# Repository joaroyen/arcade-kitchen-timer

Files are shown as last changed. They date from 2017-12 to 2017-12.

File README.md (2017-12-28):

# Arcade Kitchen Timer

The Arcade Kitchen Timer Mini is my first attempt at designing and developing a product using electronics, programming and 3D modelling. See [Wiki](https://github.com/joaroyen/arcade-kitchen-timer/wiki) for details about the project.

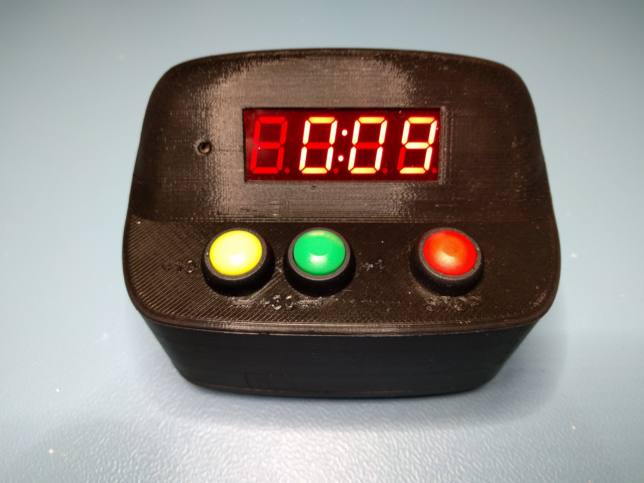
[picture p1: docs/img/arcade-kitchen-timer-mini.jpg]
Arcade Kitchen Timer Mini


> PS: Don't expect much activity in this repository after it is published.

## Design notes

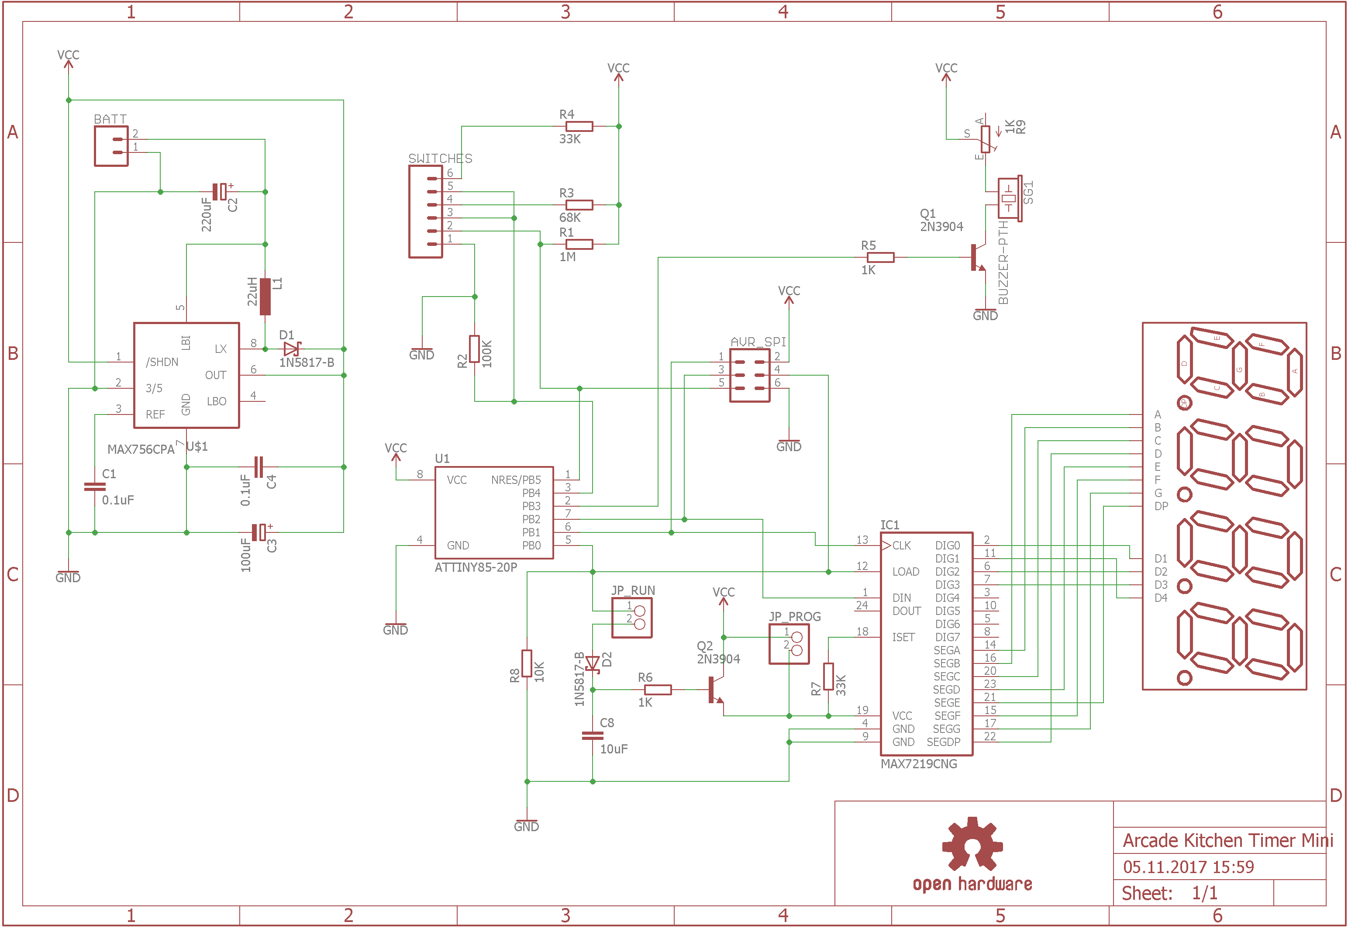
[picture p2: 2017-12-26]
docs/img/mini-electronics-schematic.png

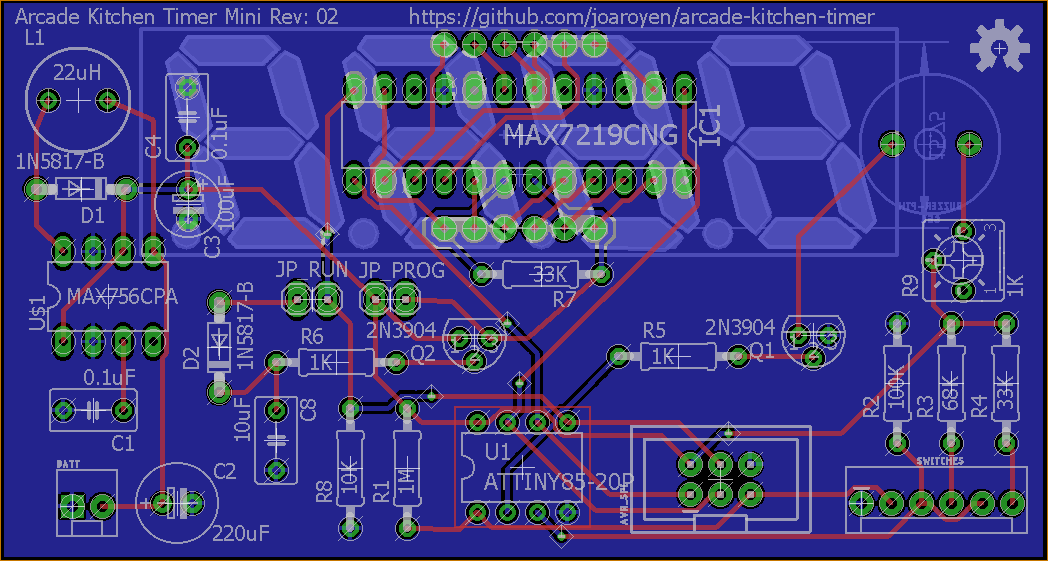
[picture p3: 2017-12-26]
docs/img/mini-electronics-board.png

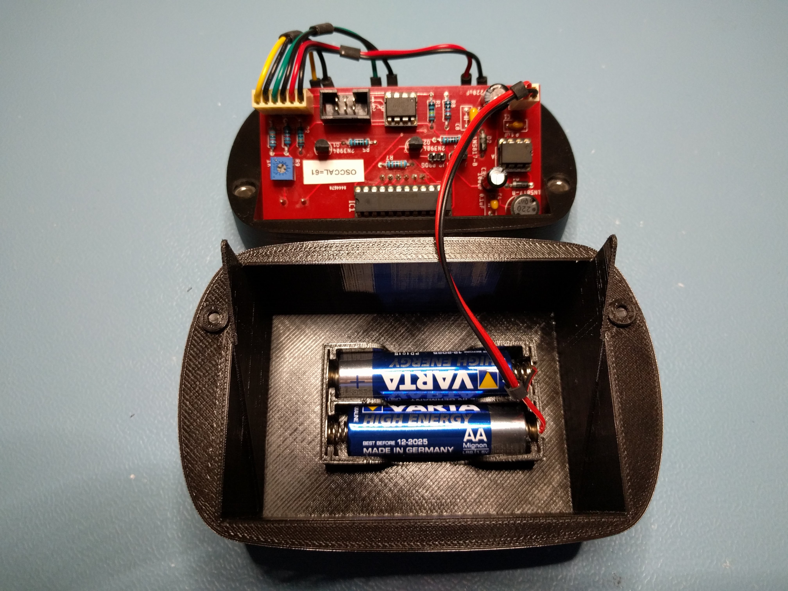
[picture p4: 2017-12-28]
docs/img/arcade-kitchen-timer-mini-open.jpg

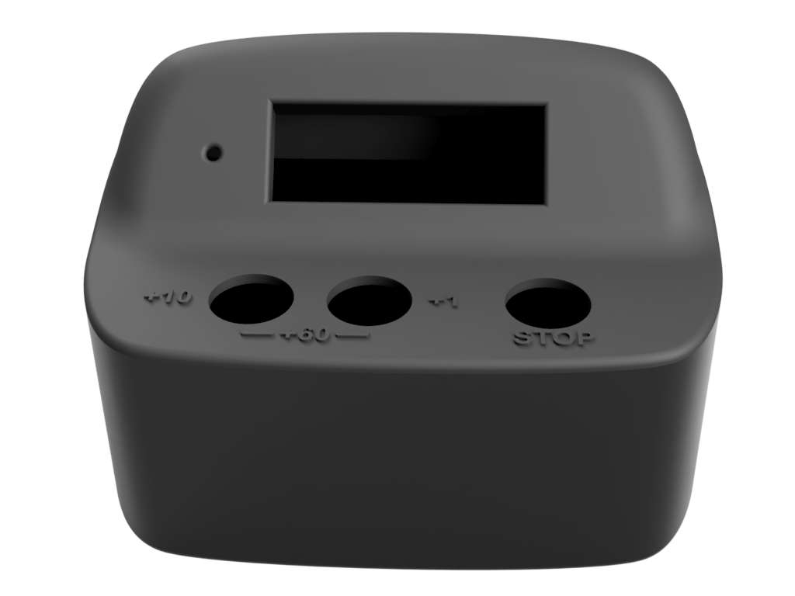
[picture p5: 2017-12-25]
docs/img/mini-enclosure-render.png

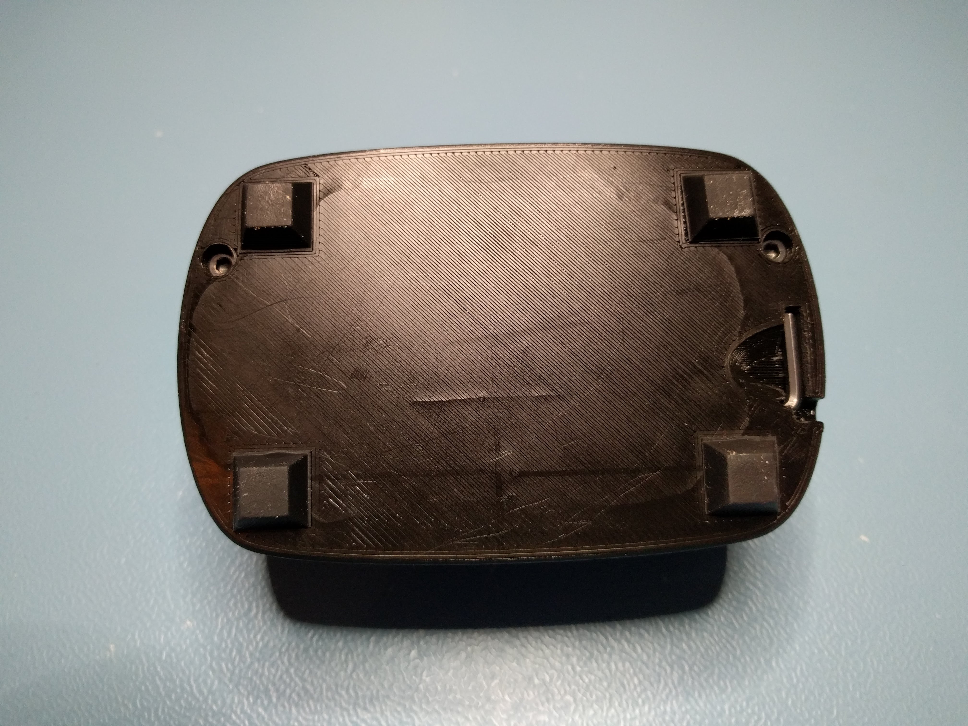
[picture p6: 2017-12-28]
docs/img/arcade-kitchen-timer-mini-bottom.jpg

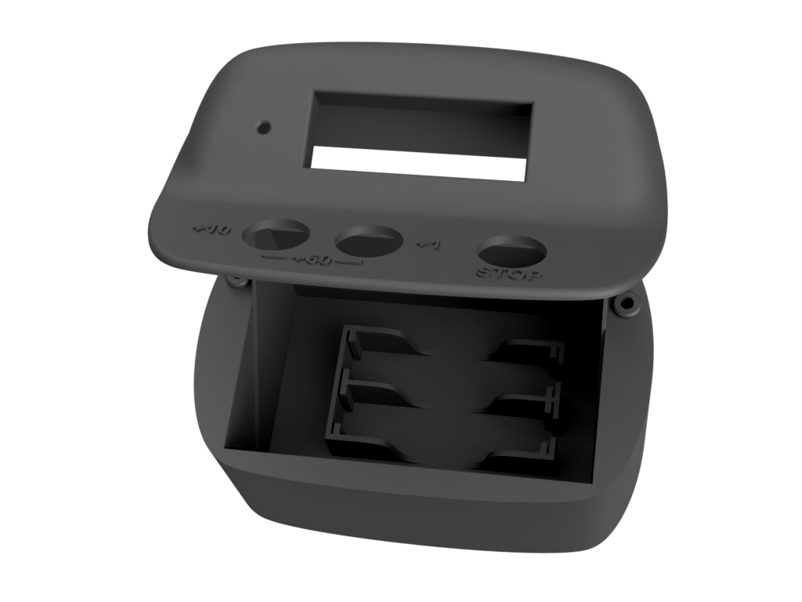
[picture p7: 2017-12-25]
docs/img/mini-enclosure-render-open.png

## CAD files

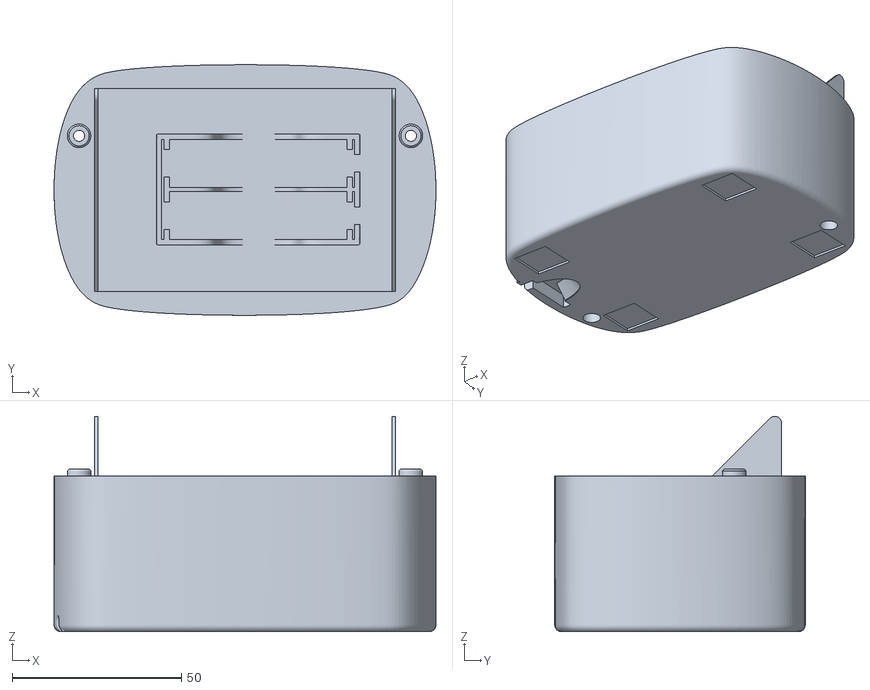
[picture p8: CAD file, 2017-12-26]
enclosure/Enclosure Case.stl
112.8 x 74.0 x 63.6

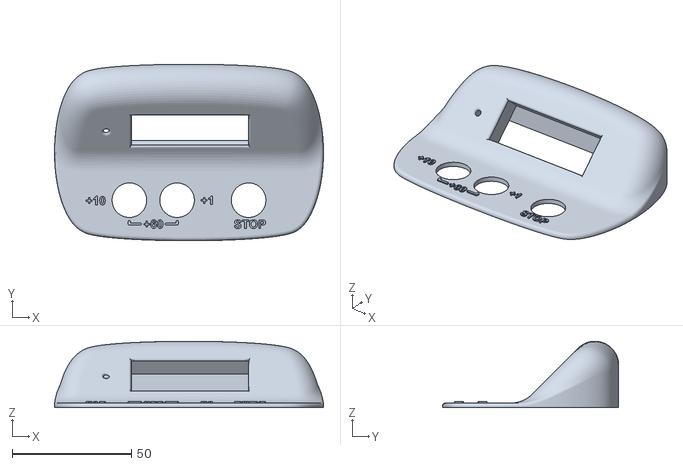
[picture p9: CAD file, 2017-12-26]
enclosure/Enclosure Top.stl
112.8 x 74.0 x 27.8

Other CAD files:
enclosure/Mini Enclosure v9.f3d

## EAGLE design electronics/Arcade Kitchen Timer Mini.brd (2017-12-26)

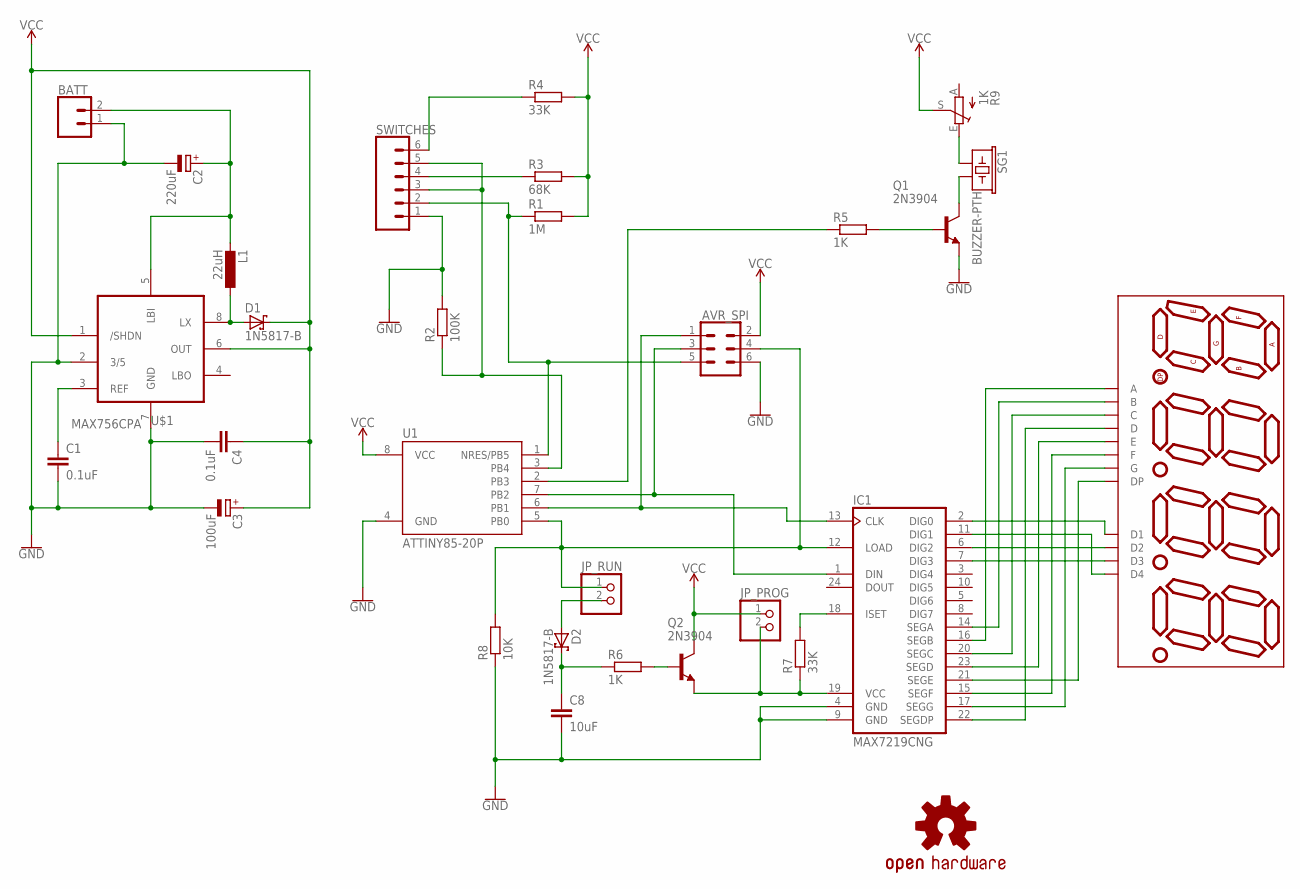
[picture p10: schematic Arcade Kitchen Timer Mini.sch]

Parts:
AVR_SPI: CONN_03X2SHROUD; 2X3-SHROUDED
BATT: CONN_02POLAR; MOLEX-1X2
C1, C4: 0.1uF; C050-035X075
C2: 220uF; E2,5-7
C3: 100uF; E2,5-6
C8: 10uF; C050-035X075
D1, D2: 1N5817-B; DO41-7.6
DISP1: ATA8041ARBJ; 7-SEGMENT-4DIGIT-20MM
IC1: MAX7219CNG; DIL24-3
JP_PROG: PINHD-1X2; 1X02
JP_RUN: PINHD-1X2; 1X02
L1: 22uH; 6000-XXXX-RC
LOGO1: OSHW-LOGOM; OSHW-LOGO-M
Q1, Q2: 2N3904; TO92
R1: 1M; 0207/10
R2: 100K; 0207/10
R3: 68K; 0207/10
R4, R7: 33K; 0207/10
R5, R6: 1K; 0207/10
R8: 10K; 0207/10
R9: 1K; B25P
SG1: BUZZER-PTH; BUZZER-12MM
SWITCHES: CONN_06POLAR; MOLEX-1X6
U1: ATTINY85-20P; PDIP08_300MIL
U$1: MAX756CPA; DIL08

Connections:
GND: AVR_SPI.6, BATT.1, C1.2, C2.-, C3.-, C4.2, C8.2, IC1.4 (GND), IC1.9 (GND), Q1.3 (E), R2.2, R8.1, SWITCHES.1, U1.4 (GND), U$1.2 (3/5), U$1.7 (GND)
unnamed: D1.A, L1.1, U$1.8 (LX)
unnamed: R5.1, U1.2 (PB3)
unnamed: R3.1, SWITCHES.4
unnamed: Q1.2 (B), R5.2
unnamed: AVR_SPI.5, R1.1, SWITCHES.2, U1.1 (NRES/PB5)
unnamed: D2.A, JP_RUN.2
unnamed: R4.1, SWITCHES.6
unnamed: Q2.2 (B), R6.2
unnamed: C1.1, U$1.3 (REF)
unnamed: Q1.1 (C), SG1.- (2)
unnamed: R9.E, SG1.+ (1)
unnamed: AVR_SPI.3, IC1.1 (DIN), U1.7 (PB2)
unnamed: IC1.18 (ISET), R7.2
unnamed: C8.1, D2.C, R6.1
unnamed: AVR_SPI.1, IC1.13 (CLK), U1.6 (PB1)
unnamed: AVR_SPI.4, IC1.12 (LOAD), JP_RUN.1, R8.2, U1.5 (PB0)
unnamed: IC1.19 (VCC), JP_PROG.2, Q2.3 (E), R7.1
unnamed: DISP1.11 (A), IC1.16 (SEGB)
unnamed: DISP1.7 (B), IC1.14 (SEGA)
unnamed: DISP1.4 (C), IC1.20 (SEGC)
unnamed: DISP1.2 (D), IC1.22 (SEGDP)
unnamed: DISP1.1 (E), IC1.23 (SEGD)
unnamed: DISP1.10 (F), IC1.15 (SEGF)
unnamed: DISP1.5 (G), IC1.17 (SEGG)
unnamed: DISP1.3 (DP), IC1.21 (SEGE)
unnamed: DISP1.12 (D1), IC1.2 (DIG0)
unnamed: DISP1.9 (D2), IC1.6 (DIG2)
unnamed: DISP1.8 (D3), IC1.7 (DIG3)
unnamed: DISP1.6 (D4), IC1.11 (DIG1)
unnamed: BATT.2, C2.+, L1.2, U$1.5 (LBI)
unnamed: R2.1, SWITCHES.3, SWITCHES.5, U1.3 (PB4)
VCC: AVR_SPI.2, C3.+, C4.1, D1.C, JP_PROG.1, Q2.1 (C), R1.2, R3.2, R4.2, R9.S, U1.8 (VCC), U$1.1 (/SHDN), U$1.6 (OUT)

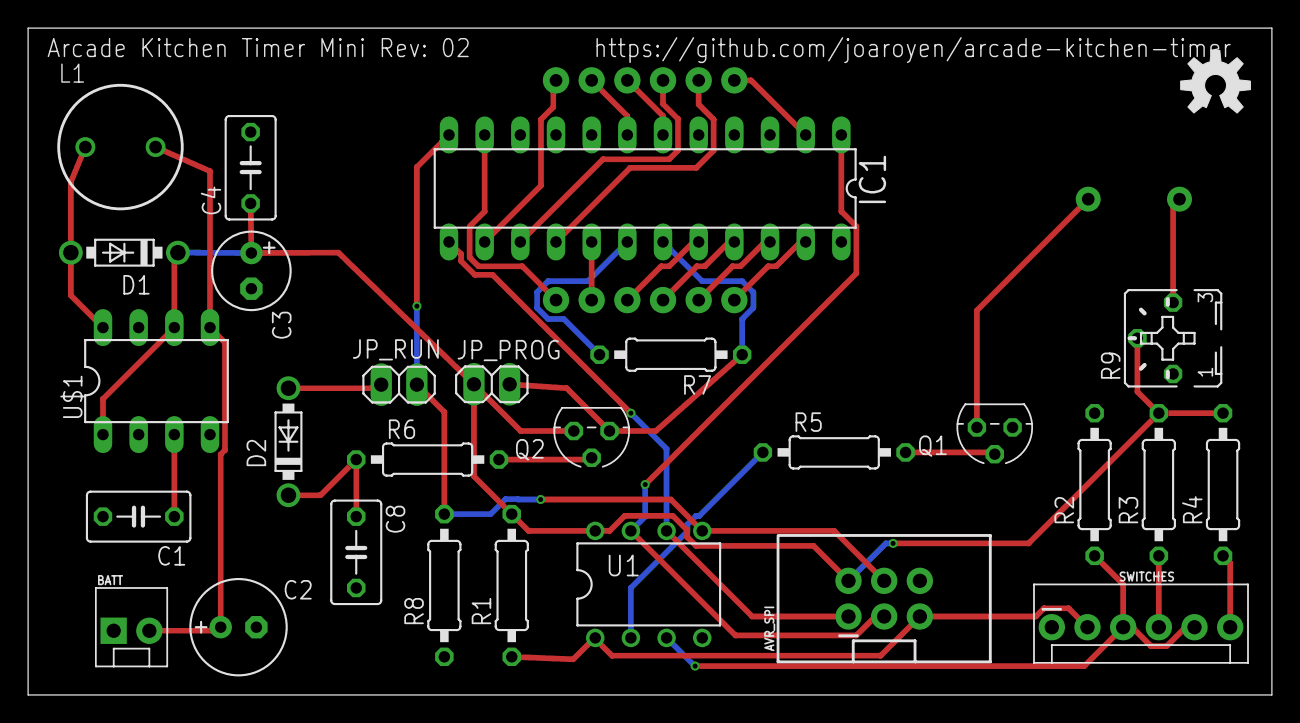
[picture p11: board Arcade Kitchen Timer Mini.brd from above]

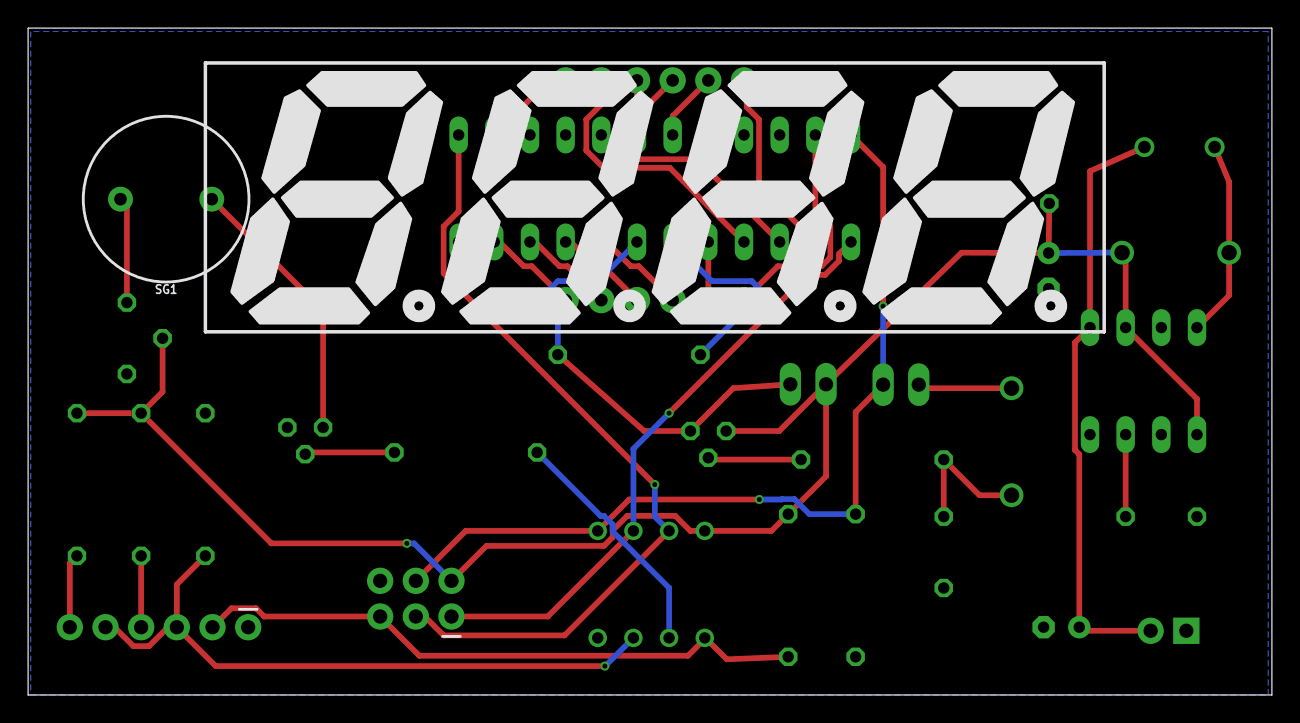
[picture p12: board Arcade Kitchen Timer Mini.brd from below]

Board: 2 copper layers, 88.6 x 47.5 mm, 30 parts (2 on the bottom side), 33 nets.

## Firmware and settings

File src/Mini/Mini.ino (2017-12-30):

#include "Common.h"
#include "Timer.h"
#include "Input.h"
#include "Display.h"
#include "Power.h"
#include "Audio.h"

Timer timer = Timer();
Input input = Input(&timer);
Display display = Display(&timer);
Power power = Power(&timer);
Audio audio = Audio(&timer);

void setup() {
  OSCCAL = DEVICE_OSCILLATOR_CALIBRATION;

  display.initialize();
  sleep();
}

void loop() {
  timer.update();

  input.read();
  display.update();
  audio.update();
  
  power.thinkAboutGoingToSleep();
}

void sleep() {
  display.shutdown();
  power.sleep();
  
  input.wakeUp();
  display.wakeUp();
  audio.wakeUp();
}

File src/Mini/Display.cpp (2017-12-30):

#include "Common.h"
#include "Display.h"


static const byte SCAN_LIMIT = B011;

static const byte DATA_PIN = 2;
static const byte CLOCK_PIN = 1;
static const byte LOAD_PIN = 0;

static const byte MAX7219_OP_DIGIT_0 = 1;
static const byte MAX7219_OP_DIGIT_1 = 3;
static const byte MAX7219_OP_DIGIT_2 = 4;
static const byte MAX7219_OP_DIGIT_3 = 2;
static const byte MAX7219_OP_DECODEMODE = 9;
static const byte MAX7219_OP_INTENSITY = 10;
static const byte MAX7219_OP_SCANLIMIT = 11;
static const byte MAX7219_OP_SHUTDOWN = 12;
static const byte MAX7219_OP_DISPLAYTEST = 15;

static const byte LED_SEGMENTS_SPACE = B00000000;
// Not using one-to-one segment mapping to improve PCB routing
static const byte LED_SEGMENTS_DIGITS[] = { 
  B11111110, 
  B01010100, 
  B11101101,
  B11110101,
  B01010111,
  B10110111,
  B10111111,
  B01110100,
  B11111111,
  B11110111
};

Display::Display(Timer* timer) {
  _timer = timer;
}

void Display::wakeUp() {
  initialize(); 
  on();
}

void Display::shutdown() {
  off();
  pinMode(DATA_PIN, INPUT);
  pinMode(CLOCK_PIN, INPUT);
  pinMode(LOAD_PIN, INPUT);
}

void Display::update() {
  int seconds = _timer->getSecondsRemaining();
  if (seconds <= 0) {
    seconds = 0;
    if (_timer->isRunning()) {
      flashDisplay();
    }
  }
  else if (!_previousState){
    on();
    _previousState = true;
  }

  
  if (seconds == _previousUpdateSeconds) return;
  _previousUpdateSeconds = seconds;

  adjustIntensity(seconds);
  if (seconds >= 3600) {
    writeHoursAndMinutes(seconds);
  }
  else {
    writeMinutesAndSeconds(seconds);
  }
}

void Display::initialize() {
  _previousUpdateSeconds = -9999;
  _previousState = false;
  _previousIntensity = DISPLAY_INTENSITY_HIGH;

  pinMode(DATA_PIN, OUTPUT);
  pinMode(CLOCK_PIN, OUTPUT);
  pinMode(LOAD_PIN, OUTPUT);
  digitalWrite(LOAD_PIN, HIGH);

  spiTransfer(MAX7219_OP_DISPLAYTEST, 0);
  spiTransfer(MAX7219_OP_SCANLIMIT, SCAN_LIMIT);
  spiTransfer(MAX7219_OP_DECODEMODE, 0);
  spiTransfer(MAX7219_OP_INTENSITY, DISPLAY_INTENSITY_HIGH);
  writeTime(0, 0);
}

void Display::on() {
  spiTransfer(MAX7219_OP_DISPLAYTEST, 0);
  spiTransfer(MAX7219_OP_SCANLIMIT, SCAN_LIMIT);
  spiTransfer(MAX7219_OP_DECODEMODE, 0);

  spiTransfer(MAX7219_OP_SHUTDOWN, 1);
}

void Display::off() {
  spiTransfer(MAX7219_OP_SHUTDOWN, 0);
}

void Display::writeHoursAndMinutes(int seconds) {
  writeTime(seconds / 3600, (seconds / 60) % 60);
}

void Display::writeMinutesAndSeconds(int seconds) {
  writeTime((seconds / 60) % 60, seconds % 60);
}

void Display::writeTime(int upper, int lower) {
  byte firstDigit = upper / 10;
  if (firstDigit == 0) {
    spiTransfer(MAX7219_OP_DIGIT_0, LED_SEGMENTS_SPACE);
  }
  else {
    spiTransfer(MAX7219_OP_DIGIT_0, LED_SEGMENTS_DIGITS[firstDigit]);
  }
  spiTransfer(MAX7219_OP_DIGIT_1, LED_SEGMENTS_DIGITS[upper % 10]);
  spiTransfer(MAX7219_OP_DIGIT_2, LED_SEGMENTS_DIGITS[lower / 10]);
  spiTransfer(MAX7219_OP_DIGIT_3, LED_SEGMENTS_DIGITS[lower % 10]);
}

void Display::spiTransfer(byte opcode, byte data) {
  digitalWrite(LOAD_PIN, LOW);
  shiftOut(DATA_PIN, CLOCK_PIN, MSBFIRST, opcode);
  shiftOut(DATA_PIN, CLOCK_PIN, MSBFIRST, data);
  digitalWrite(LOAD_PIN, HIGH);
}

void Display::flashDisplay() {
  if (millis() % 1000 > 400) {
    if (!_previousState) {
      on();
      _previousState = true;
    }
  }
  else if (_previousState) {
    off();
    _previousState = false;
  }
}

void Display::adjustIntensity(int seconds) {
  if (!_timer->isRunning() || seconds <= 60 || seconds % 60 == 0) {
      if (_previousIntensity != DISPLAY_INTENSITY_HIGH) {
        spiTransfer(MAX7219_OP_INTENSITY, DISPLAY_INTENSITY_HIGH);
        _previousIntensity = DISPLAY_INTENSITY_HIGH;
      }
  }
  else {
      if (_previousIntensity != DISPLAY_INTENSITY_LOW) {
        spiTransfer(MAX7219_OP_INTENSITY, DISPLAY_INTENSITY_LOW);
        _previousIntensity = DISPLAY_INTENSITY_LOW;
      }
  }
}

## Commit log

2017-12-25 Renderer of open enclosure
2017-12-26 Adding enclosure 3D model files
    [Enclosure Case.stl, Enclosure Top.stl, Mini Enclosure v9.f3d]
2017-12-26 Added electronics files
    [Arcade Kitchen Timer Mini.brd, Arcade Kitchen Timer Mini.sch]
2017-12-30 Arcate Kitchen Timer Mini sketch
2017-12-30 Moved into separate Mini folder to support Arduino editor

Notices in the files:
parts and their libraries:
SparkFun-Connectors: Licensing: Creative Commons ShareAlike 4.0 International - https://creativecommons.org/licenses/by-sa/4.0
